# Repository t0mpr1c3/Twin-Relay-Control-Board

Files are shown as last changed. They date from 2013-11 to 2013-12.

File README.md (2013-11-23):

Twin-Relay-Control-Board
========================

Control board for two NAIS JSM1A or Songle SRD NO relays on Dangerous Prototypes DP5050 standard PCB size.

Derived from Sparkfun Electronics COM-11041 designed by N. Seidle and Joel Bartlett.

The component values are designed for VCC = 5 VDC. For VCC = 12 VDC, R4/R5 = 3.3K.

Released under Creative Commons Attribution Share-Alike 3.0 License. http://creativecommons.org/licenses/by-sa/3.0

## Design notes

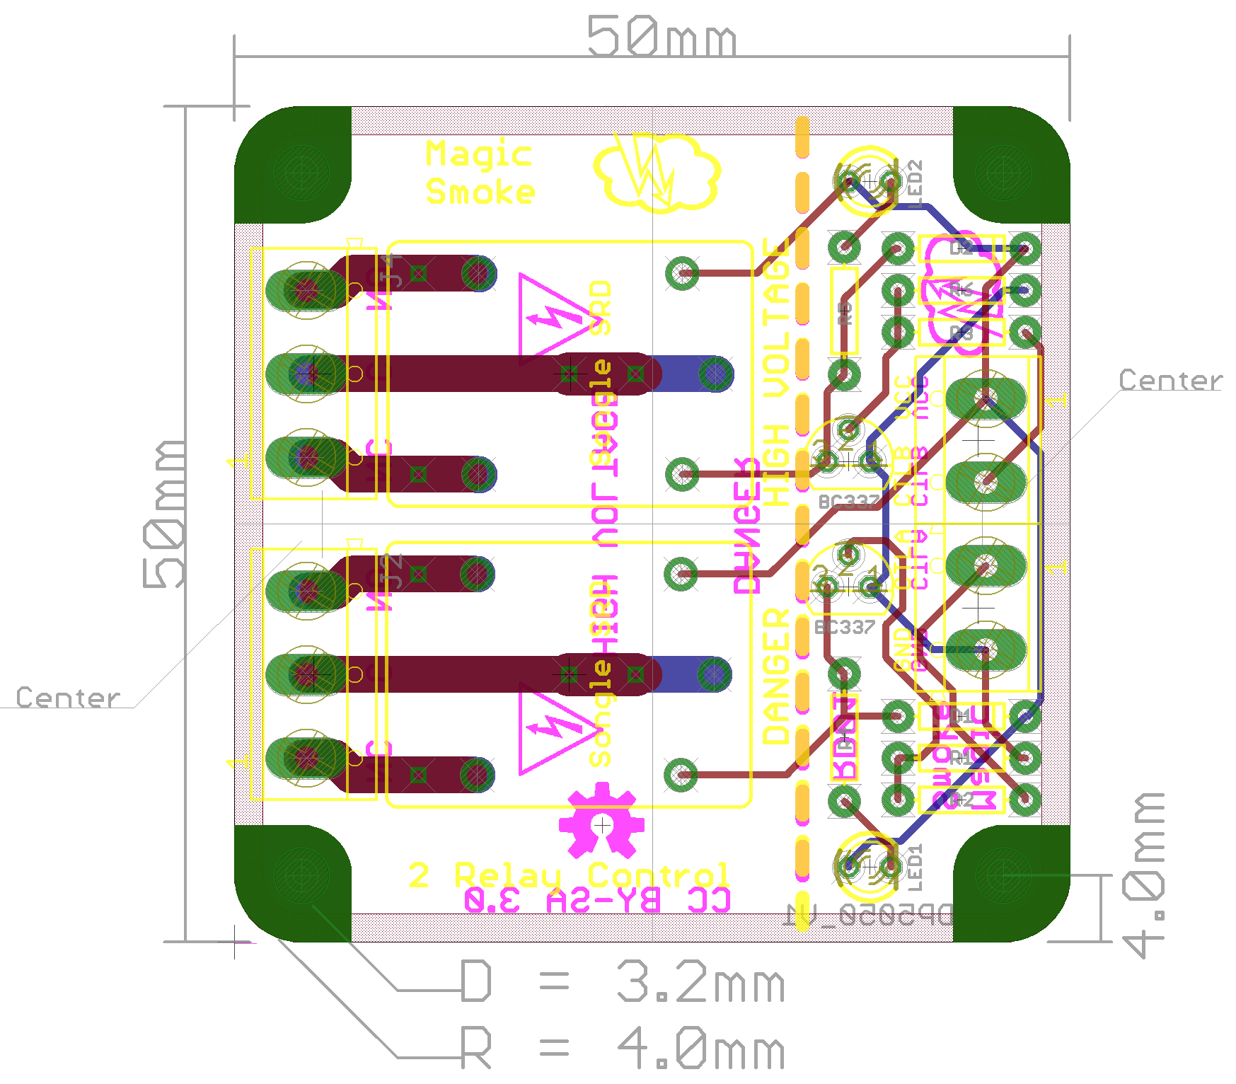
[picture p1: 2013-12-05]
hardware/RD01/RD01-brd.png

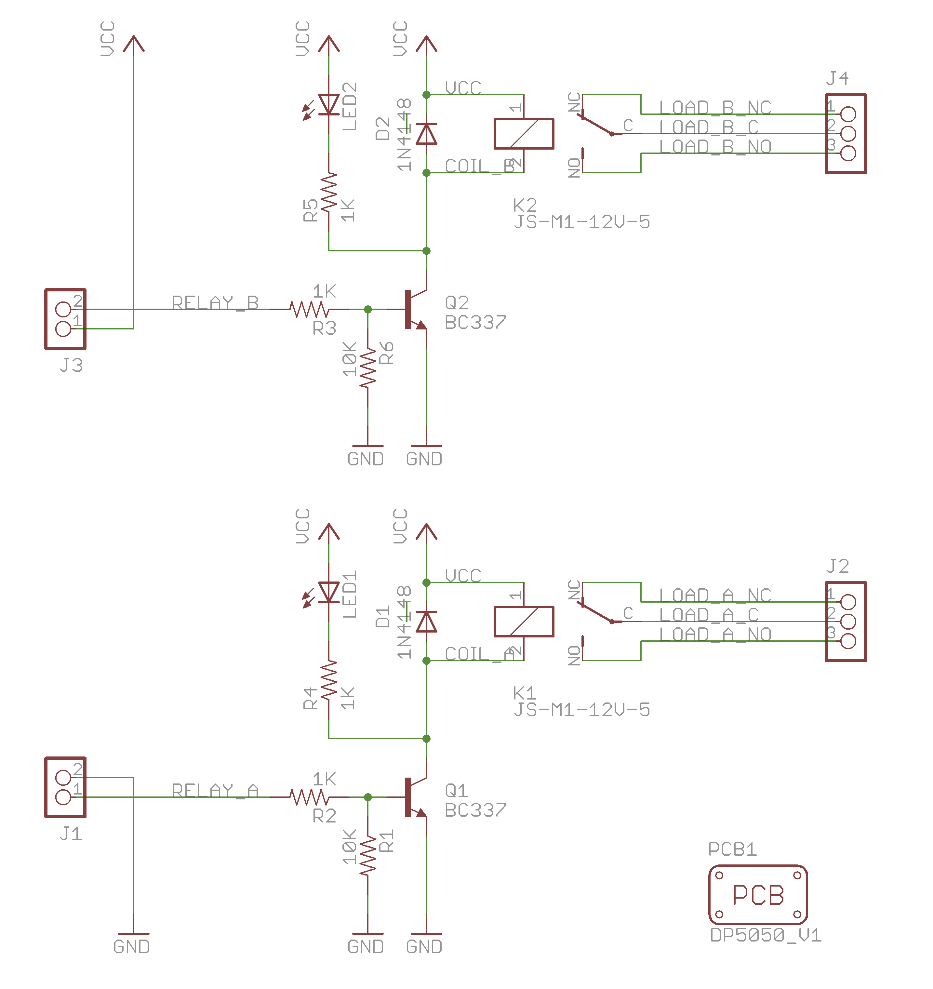
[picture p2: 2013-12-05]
hardware/RD01/RD01-sch.png

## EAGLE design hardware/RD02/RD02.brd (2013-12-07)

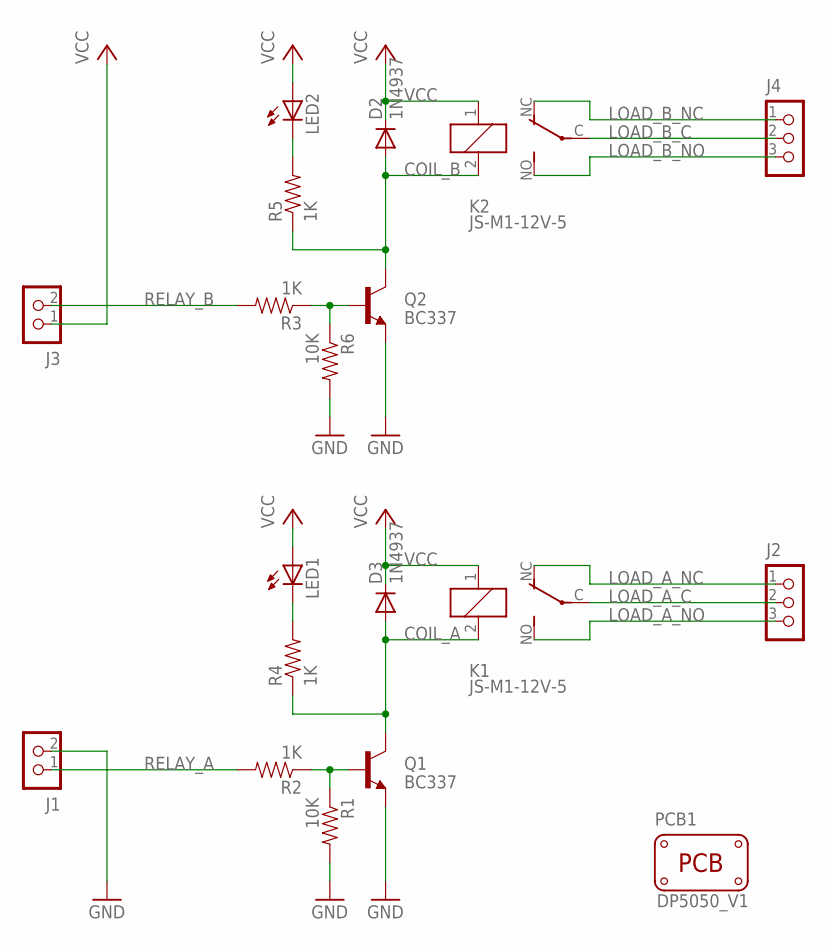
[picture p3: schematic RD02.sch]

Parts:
D2, D3: 1N4937; DO41-10
J1, J3: CON_TERMINAL_BLOCK_02-5MM; TERMINAL_BLOCK_2P_5
J2, J4: CON_TERMINAL_BLOCK_03-5MM; TERMINAL_BLOCK_3P_5
K1, K2: JS-M1-12V-5; JS-M; MPN JSM1-12V-5
LED1, LED2: LED-3MM
PCB1: PCB_DP_SQUARE-5X5; DP5050_V1
Q1, Q2: BC337; TO92
R1, R6: 10K; AXIAL-0.3
R2, R3, R4, R5: 1K; AXIAL-0.3

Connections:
COIL_A: D3.A, K1.2, Q1.3 (C), R4.P$1 (1)
COIL_B: D2.A, K2.2, Q2.3 (C), R5.P$1 (1)
GND: J1.2, Q1.1 (E), Q2.1 (E), R1.P$2 (2), R6.P$2 (2)
LOAD_A_C: J2.2, K1.C
LOAD_A_NC: J2.1, K1.NC (O)
LOAD_A_NO: J2.3, K1.NO (S)
LOAD_B_C: J4.2, K2.C
LOAD_B_NC: J4.1, K2.NC (O)
LOAD_B_NO: J4.3, K2.NO (S)
unnamed: Q2.2 (B), R3.P$1 (1), R6.P$1 (1)
unnamed: LED2.K (C), R5.P$2 (2)
unnamed: Q1.2 (B), R1.P$1 (1), R2.P$1 (1)
unnamed: LED1.K (C), R4.P$2 (2)
RELAY_A: J1.1, R2.P$2 (2)
RELAY_B: J3.2, R3.P$2 (2)
VCC: D2.C, D3.C, J3.1, K1.1, K2.1, LED1.A, LED2.A

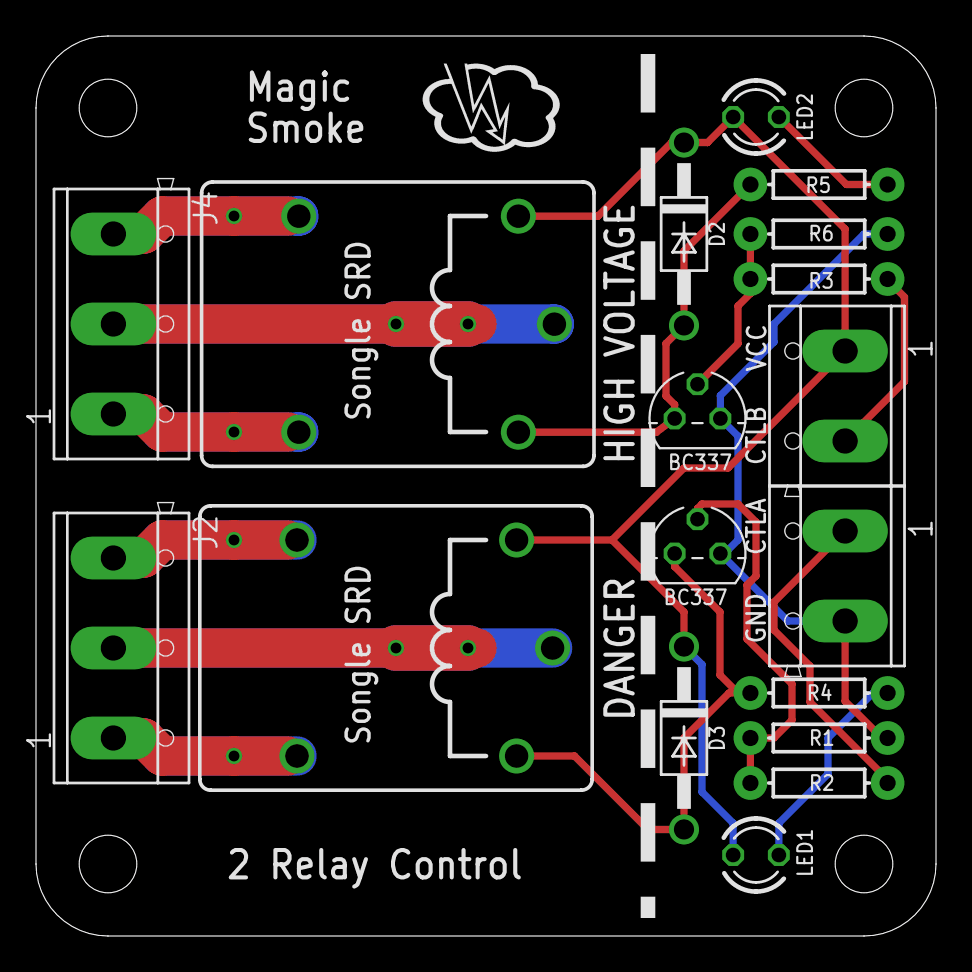
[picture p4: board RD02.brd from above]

Board: 4 copper layers, 50.0 x 50.0 mm, 20 parts (1 on the bottom side), 16 nets.

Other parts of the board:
U$2: OSHW-LOGO-M

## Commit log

2013-11-23 RB02 first draft
    [RB02.GBL, RB02.GBO, RB02.GBP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]
2013-11-23 BC337s instead of BC546s
    [RB02.brd, RB02.sch]
2013-11-25 tweak gerbers
    [RB02.brd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]
2013-11-26 JS-M1 relay package
    [RB02.brd, RB02.sch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]
2013-11-30 reorganize folders
    [RD01.GBL, RD01.GBO, RD01.GBP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]
2013-12-03 2mm clearance
    [RD01.brd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]
2013-12-05 RD01 Elecrow order
    [RD01.brd, RD01.sch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]
2013-12-07 faster higher power diode closer to coil
    [RD02.brd, RD02.sch]

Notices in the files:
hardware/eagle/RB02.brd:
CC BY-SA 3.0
